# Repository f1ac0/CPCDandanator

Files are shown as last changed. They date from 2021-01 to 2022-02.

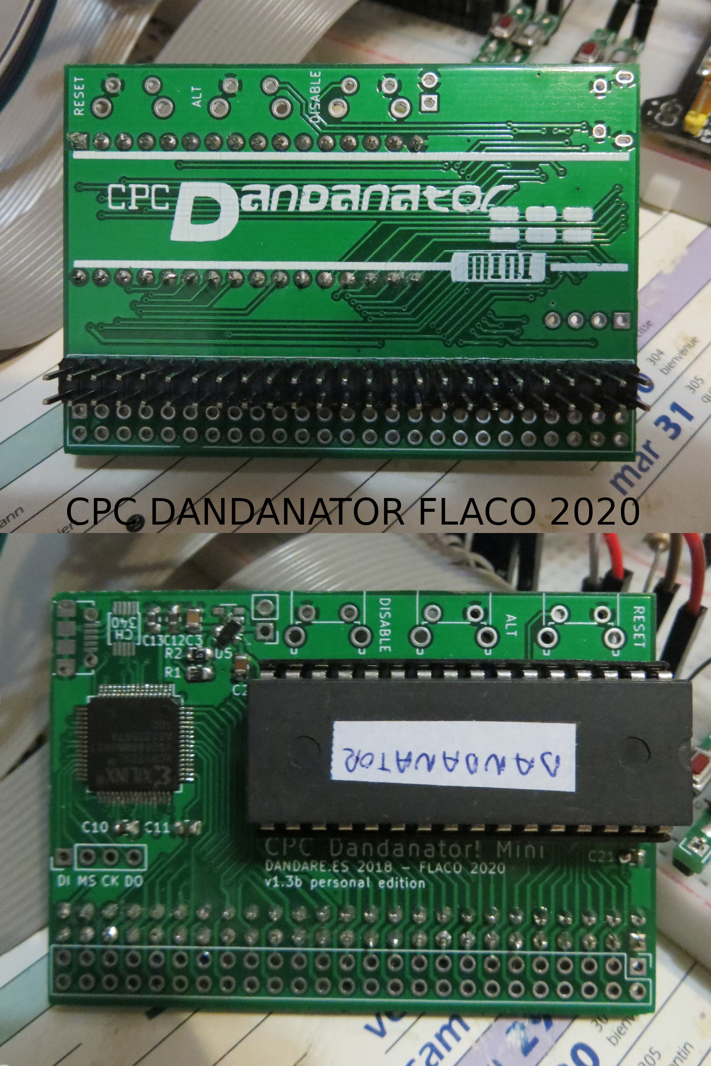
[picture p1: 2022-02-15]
CPCDandanator FLACO 2020.JPG

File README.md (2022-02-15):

# CPCDandanator
This project is a personal version of the famous "CPC Dandanator! Mini" by Dandare : http://www.dandare.es/Proyectos_Dandare/CPC_Dandanator%21_Mini.html .

Facts about this project :
- I wanted badly to try out "Sword of Ianna", so I built it on breadboard with the parts I had in stock :
- Flash ROM in DIP format,
- XC9572XL in VQ64 package (although Kicad files with VQ44 are also provided).

It ended on its own PCB with additional changes : 
- It can accommodate a card-edge connector or a pin header.
- I used a crystal-less CH340E to reduce BOM. WARNING: serial/USB communication does not work for me :( 

# Disclaimer
This is a hobbyist project, it comes with no warranty and no support. Also remember that the Amstrad machines are about 30 years old and may fail because of such hardware expansions.

The original "CPC Dandanator! Mini" is "a Public Domain project and all code/hardware/description is free to use with no restriction whatsoever" thanks to its author.

This version is not connected to Dandare, please don't bother him with issues you might have because of it.

If you find it useful and want to reward someone : reward the original author.

# BOM
- 1x XC9572XL CPLD
- 1x DIP SST39SF040, with socket
- 1x CH340E USB-serial converter + 1x micro USB connector
- 1x 3.3v LDO, either SPX3819M5-L-3-3 or XC6206P332MR
- 2x 1uF (or more) 0805 capacitors
- 5x 100nF 0805 capacitors
- 2x 10k 0805 resistor
- 1x 50 pins card-edge connector, or pin headers + cable to match your CPC

# Making it
Components are SMD, and have thin pin pitch. You need to know what you are doing.

Check for shorts at least between 5V, 3.3V, and GND traces before applying power !

The programming port does not need to be soldered since it needs to be programmed just once : you can just hold it in place during the few seconds required for programming.

XC9572XL code is generated and built into xsvf using Xilinx ISE 14.7 IDE then iMPACT. It requires to set "Logic optimization" to "Density". "Macrocell power setting" can be "Low" an "Slew rate" to "Slow". Original xsvf file provided by the author may work but I never tried it.

There are several methods to program the CPLD. I personally use xsvfduino : https://github.com/wschutzer/xsvfduino

CH340E and USB connector are optional if you do not plan to use USB. They dit not work for me anyway.

# Using it
This part is the same as the original device. Enjoy !

If you are a linux user like me, here is a tip to use the java application on modern systems without breaking the latest openjre provided by your distro :
- get oracle jre (for example from http://download.macromedia.com/pub/coldfusion/java/java8/8u271/jre/jre-8u271-linux-x64.tar.gz) and untar it
- start the app with ```~/jre1.8.0_271/bin/java -jar dandanator-cpc-2.3.jar```

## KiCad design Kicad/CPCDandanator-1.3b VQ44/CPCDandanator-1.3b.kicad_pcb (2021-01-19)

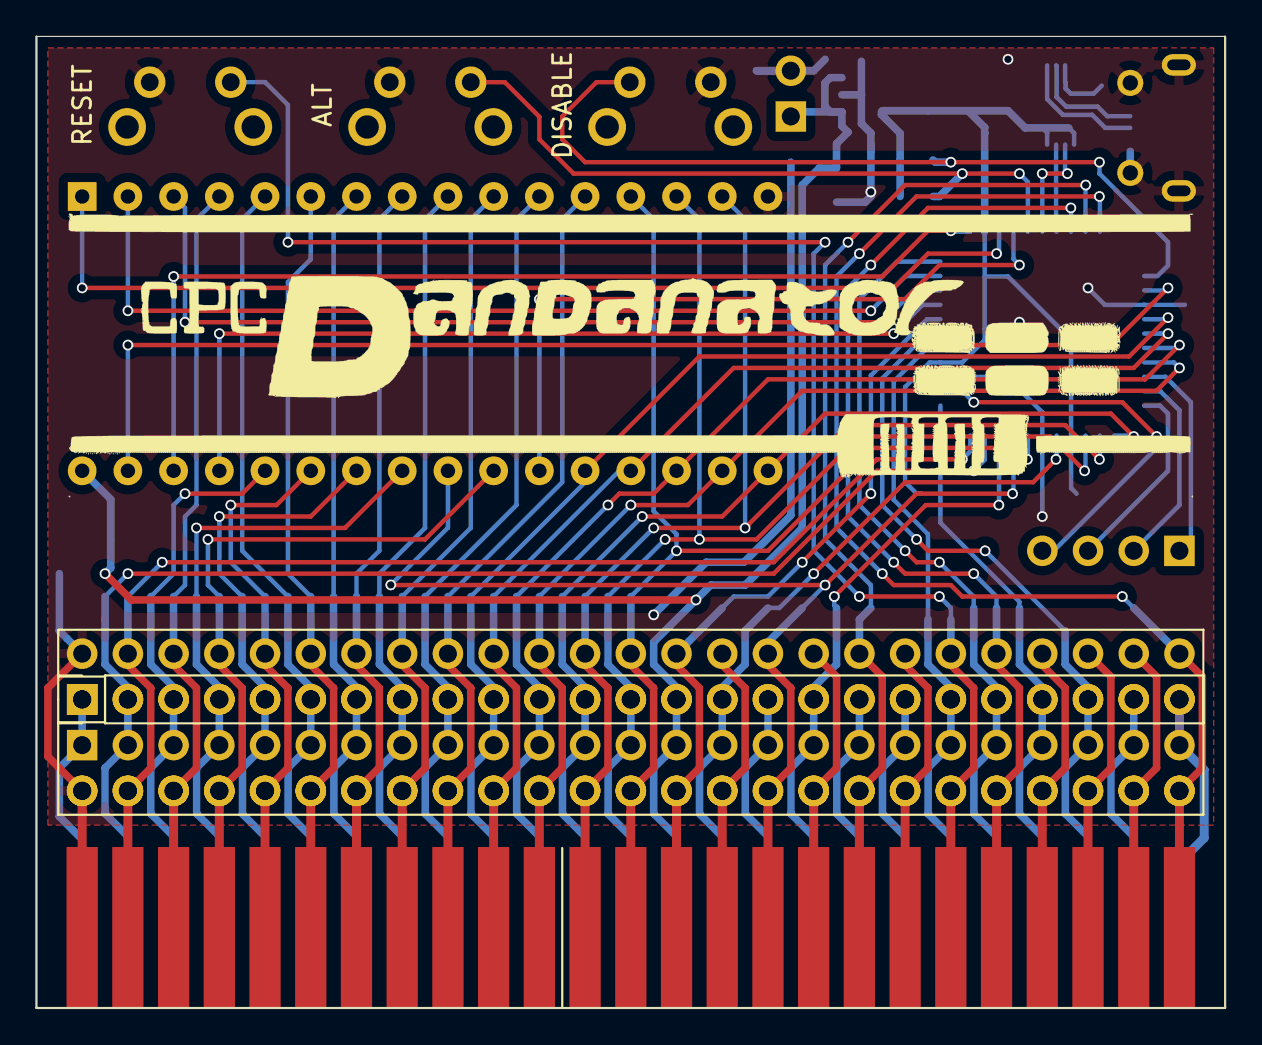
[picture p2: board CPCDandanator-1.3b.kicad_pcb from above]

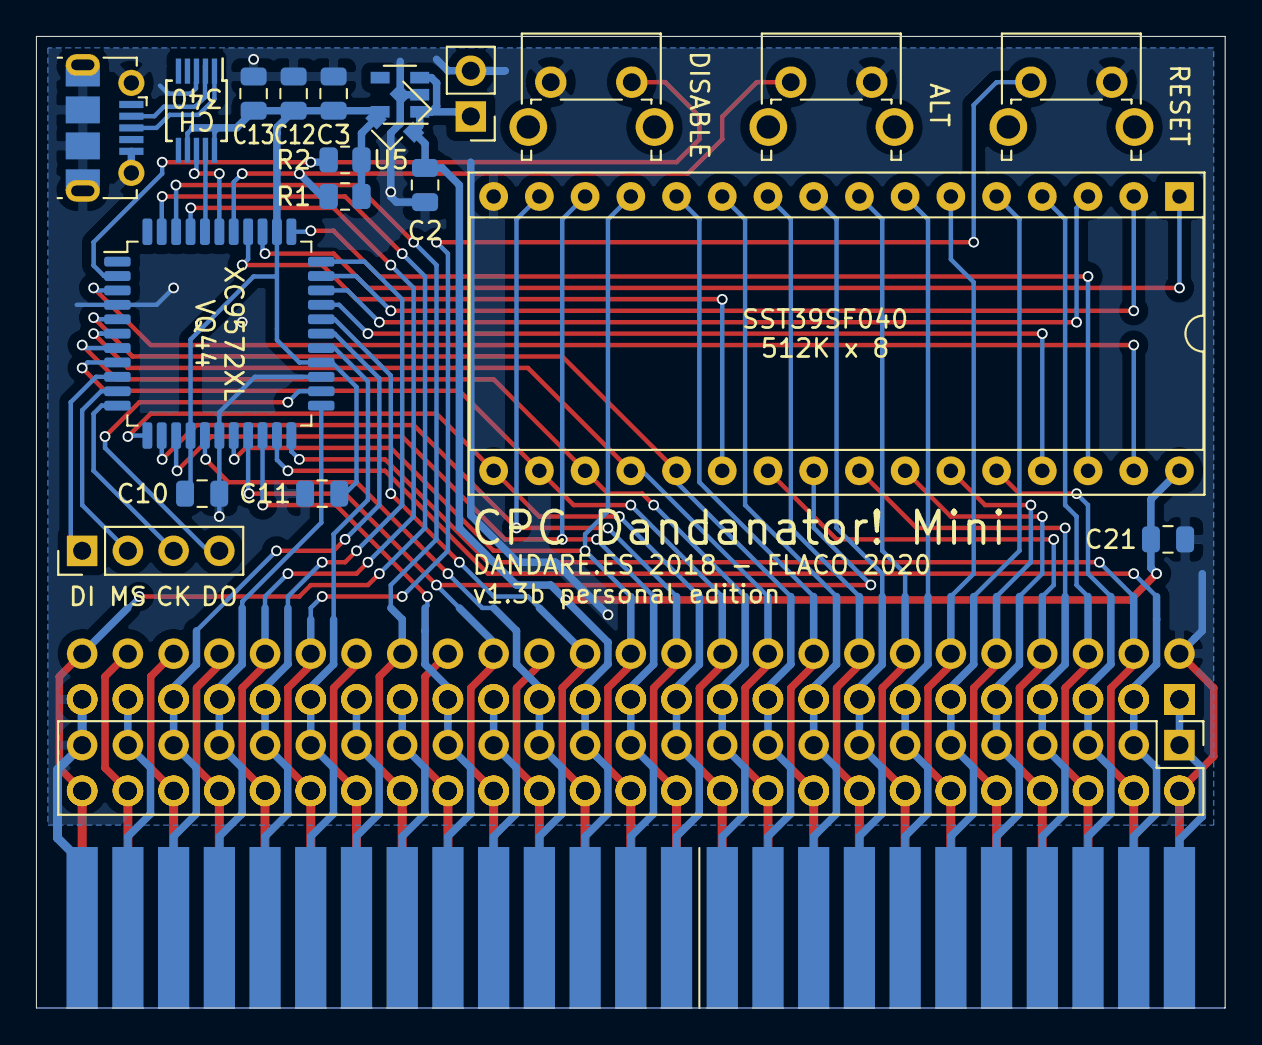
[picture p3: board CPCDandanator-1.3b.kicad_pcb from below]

Board: 2 copper layers, 66.0 x 54.0 mm, 25 parts (22 on the bottom side), 67 nets.

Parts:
C2, C3: 10uF; C_0805_2012Metric
C10, C11, C12, C13, C21: 100n; C_0805_2012Metric
FID1: Logo; PIC_Dandanator_FS_B
J1: TO CPC CARD EDGE; CPC_ExpansionSocket_2x25_P2.54mm_5mm
J2: TO CPC MX-4 ribbon; PinHeader_2x25_P2.54mm_Vertical
J3: POWER; PinHeader_1x02_P2.54mm_Vertical
J4: CPLD_JTAG; PinHeader_1x04_P2.54mm_Vertical
J5: USB_B_Micro; USB_Micro-B_Molex-105017-0001
J8: FROM EXPANSION; BUS_Amstrad_CPC_Expansion_2x25_2.54mm
J9: FROM EXPANSION; PinHeader_2x25_P2.54mm_Vertical
R1, R2: 10k; R_0805_2012Metric
SW1: RESET; SW_Tactile_SPST_Angled_PTS645Vx39-2LFS
SW3: ALTERNATE; SW_Tactile_SPST_Angled_PTS645Vx39-2LFS
SW4: DISABLE; SW_Tactile_SPST_Angled_PTS645Vx39-2LFS
U1: XC9572XL-VQ44; LQFP-44_10x10mm_P0.8mm
U3: 29C040; DIP-32_W15.24mm_Socket
U5: SPX3819M5-L-3-3; SOT-23-5
U12: CH340E; MSOP-10_3x3mm_P0.5mm
U15: XC6206PxxxMR; SOT-23

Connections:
+3V3: C3.1, C10.1, C11.1, C12.1, C13.1, R1.1, R2.1, U1.15, U1.26, U1.35, U5.5, U12.7, U12.10, U15.2
+5V: C2.1, C21.1, J1.27, J2.27, J3.1, J8.27, J9.27, U3.32, U5.1, U5.3, U15.3
/A0: J1.18, J2.18, J8.18, J9.18, U3.12
/A1: J1.17, J2.17, J8.17, J9.17, U3.11
/A2: J1.16, J2.16, J8.16, J9.16, U3.10
/A3: J1.15, J2.15, J8.15, J9.15, U3.9
/A4: J1.14, J2.14, J8.14, J9.14, U3.8
/A5: J1.13, J2.13, J8.13, J9.13, U3.7
/A6: J1.12, J2.12, J8.12, J9.12, U3.6
/A7: J1.11, J2.11, J8.11, J9.11, U3.5
/A8: J1.10, J2.10, J8.10, J9.10, U3.27
/A9: J1.9, J2.9, J8.9, J9.9, U3.26
/A10: J1.8, J2.8, J8.8, J9.8, U3.23
/A11: J1.7, J2.7, J8.7, J9.7, U3.25
/A12: J1.6, J2.6, J8.6, J9.6, U3.4
/A13: J1.5, J2.5, J8.5, J9.5, U3.28
/A14: J1.4, J2.4, J8.4, J9.4, U1.22
/A15: J1.3, J2.3, J8.3, J9.3, U1.21
/BRST: J1.40, J2.40, J8.40, J9.40, SW1.1
/BUSAK: J1.38, J2.38, J8.38, J9.38
/BUSRQ: J1.37, J2.37, J8.37, J9.37
/BUTTON: R1.2, SW3.1, U1.38
/BUTTON2: R2.2, SW4.2, U1.2
/CLK4: J1.50, J2.50, J8.50, J9.50, U1.43
/CURSOR: J1.46, J2.46, J8.46, J9.46
/D0: J1.26, J2.26, J8.26, J9.26, U1.18, U3.13
/D1: J1.25, J2.25, J8.25, J9.25, U1.14, U3.14
/D2: J1.24, J2.24, J8.24, J9.24, U1.13, U3.15
/D3: J1.23, J2.23, J8.23, J9.23, U1.12, U3.17
/D4: J1.22, J2.22, J8.22, J9.22, U1.8, U3.18
/D5: J1.21, J2.21, J8.21, J9.21, U1.7, U3.19
/D6: J1.20, J2.20, J8.20, J9.20, U1.6, U3.20
/D7: J1.19, J2.19, J8.19, J9.19, U1.5, U3.21
/D+: J5.3, U12.1
/D-: J5.2, U12.2
/EXP: J1.48, J2.48, J8.48, J9.48
/HALT: J1.34, J2.34, J8.34, J9.34
/INT: J1.35, J2.35, J8.35, J9.35
/IORQ: J1.31, J2.31, J8.31, J9.31
/LPEN: J1.47, J2.47, J8.47, J9.47
/M1: J1.29, J2.29, J8.29, J9.29, U1.16
/MREQ: J1.28, J2.28, J8.28, J9.28, U1.29
/NMI: J1.36, J2.36, J8.36, J9.36, U1.42
/RAMDIS: J1.45, J2.45, J8.45, J9.45, U1.28
/RAMRD: J1.44, J2.44, J8.44, J9.44
/RD: J1.32, J2.32, J8.32, J9.32, U1.19, U3.24
/READY: J1.39, J2.39, J8.39, J9.39, U1.27
/RESET: J1.41, J2.41, J8.41, J9.41, U1.33
/RFSH: J1.30, J2.30, J8.30, J9.30
/ROMA14: U1.30, U3.29
/ROMA15: U1.31, U3.3
/ROMA16: U1.32, U3.2
/ROMA17: U1.34, U3.30
/ROMA18: U1.36, U3.1
/ROMCE: U1.37, U3.22
/ROMDIS: J1.43, J2.43, J8.43, J9.43, U1.23
/ROMEN: J1.42, J2.42, J8.42, J9.42, U1.41
/ROMWE: U1.3, U3.31
/RXD: U1.40, U12.9
/SOUND: J1.1, J2.1, J8.1, J9.1
/TCK: J4.3, U1.11
/TDI: J4.1, U1.9
/TDO: J4.4, U1.24
/TMS: J4.2, U1.10
/TXD: U1.39, U12.8
/WR: J1.33, J2.33, J8.33, J9.33, U1.20
GND: C2.2, C3.2, C10.2, C11.2, C12.2, C13.2, C21.2, J1.2, J1.49, J2.2, J2.49, J3.2, J5.5, J5.6, J8.2, J8.49, J9.2, J9.49, SW1.2, SW3.2, SW4.1, U1.4, U1.17, U1.25, U3.16, U5.2, U12.3, U15.1

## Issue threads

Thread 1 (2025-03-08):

CPLD Jed file? confirmed working rom?

Retrofletch, 2025-03-08:
Im struggling to get this working, ive built two of them and both act same way.
I used the 44pin CPLD board, edited the pinouts in CPCDandanator.ucf to match the commented ones for 44pin cpld, i changed the settings as followed ""Logic optimization" to "Density". "Macrocell power setting" can be "Low" an "Slew rate" to "Slow"" and managed to get it to fit.

CPLD was from mouser. And i connect the dandanator with components facing down as i hope is intended i checked pin1.

Everything programs and verifies but i get nothing when i turn on the machine. its such a simple device i dont know what else then cpld can be the issue here, do you have a known working 44pin jed file perhaps? Would help in ruling out a compiling error.

Also perhaps a rom file that is confirmed working?

/Fletch

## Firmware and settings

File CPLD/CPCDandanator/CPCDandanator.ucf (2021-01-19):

# ! In Fit/Implementation template, choose "Optimize Density"

PIN "Button"	LOC = P7; //P38;
PIN "Button2"	LOC = P19; //P2;

PIN "CHG_Txd"	LOC = P8; //P39;
PIN "CHG_Rxd"	LOC = P9; //P40;

PIN "nRomEN"	LOC = P10; //P41;
PIN "nM1"	LOC = P38; //P42;
PIN "nMreq"	LOC = P60; //P29;
PIN "nWr"	LOC = P44; //P20;
PIN "nRd"	LOC = P43; //P19;
PIN "Clk"	LOC = P15; //P43;
NET "Clk" BUFG = CLK;
PIN "Rdy"	LOC = P56; //P27;
PIN "A15"	LOC = P45; //P21;
PIN "A14"	LOC = P48; //P22;
PIN "nRst"	LOC = P64; //P33;
PIN "DataBus<0>"	LOC = P42; //P18;
PIN "DataBus<1>"	LOC = P36; //P14;
PIN "DataBus<2>"	LOC = P35; //P13;
PIN "DataBus<3>"	LOC = P33; //P12;
PIN "DataBus<4>"	LOC = P27; //P8;
PIN "DataBus<5>"	LOC = P25; //P7;
PIN "DataBus<6>"	LOC = P24; //P6;
PIN "DataBus<7>"	LOC = P22; //P5;
PIN "Romdis"	LOC = P50; //P23;
PIN "Ramdis"	LOC = P57; //P28;

PIN "nEp_Ce"	LOC = P6; //P37;
PIN "nEp_Wr"	LOC = P20; //P3;
PIN "Ep_A18_14<0>"	LOC = P61; //P30;
PIN "Ep_A18_14<1>"	LOC = P62; //P31;
PIN "Ep_A18_14<2>"	LOC = P63; //P32;
PIN "Ep_A18_14<3>"	LOC = P2; //P34;
PIN "Ep_A18_14<4>"	LOC = P5; //P36;

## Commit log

2021-01-19 Respository init with KiCAD files, CPLD and Readme
    [CPCDandanator-1.3b (edge connector).kicad_pcb, CPCDandanator-1.3b (no edge connector).kicad_pcb, CPCDandanator-1.3b.kicad_pcb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]
2022-02-15 Photo and README
    [CPCDandanator-1.3b (edge connector).kicad_pcb, CPCDandanator-1.3b (no edge connector).kicad_pcb, CPCDandanator-1.3b.kicad_pcb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]

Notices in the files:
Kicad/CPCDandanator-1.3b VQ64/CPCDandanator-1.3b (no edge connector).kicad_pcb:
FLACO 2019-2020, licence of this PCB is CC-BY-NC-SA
